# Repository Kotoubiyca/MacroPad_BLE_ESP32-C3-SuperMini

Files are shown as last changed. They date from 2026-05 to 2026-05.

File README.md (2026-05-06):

# MacroPad_BLE_ESP32-C3-SuperMini

Print project published at [MakerWorld](https://makerworld.com/uk/models/2765469-bluetooth-macropad)

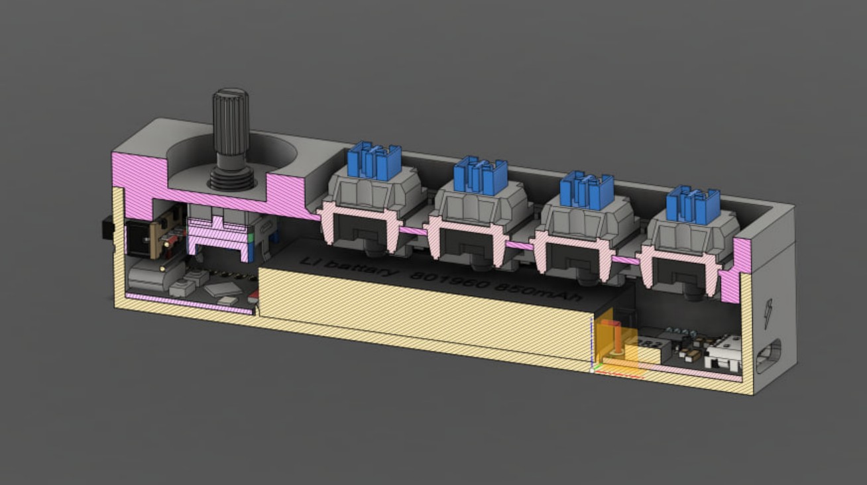
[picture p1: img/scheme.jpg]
[](/img/scheme.jpg)

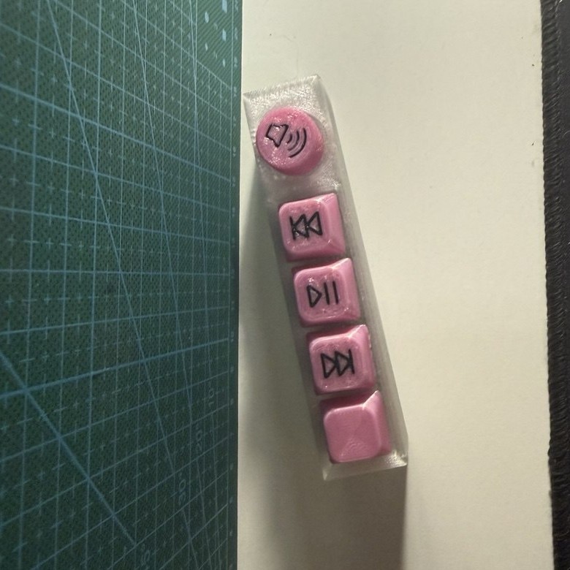
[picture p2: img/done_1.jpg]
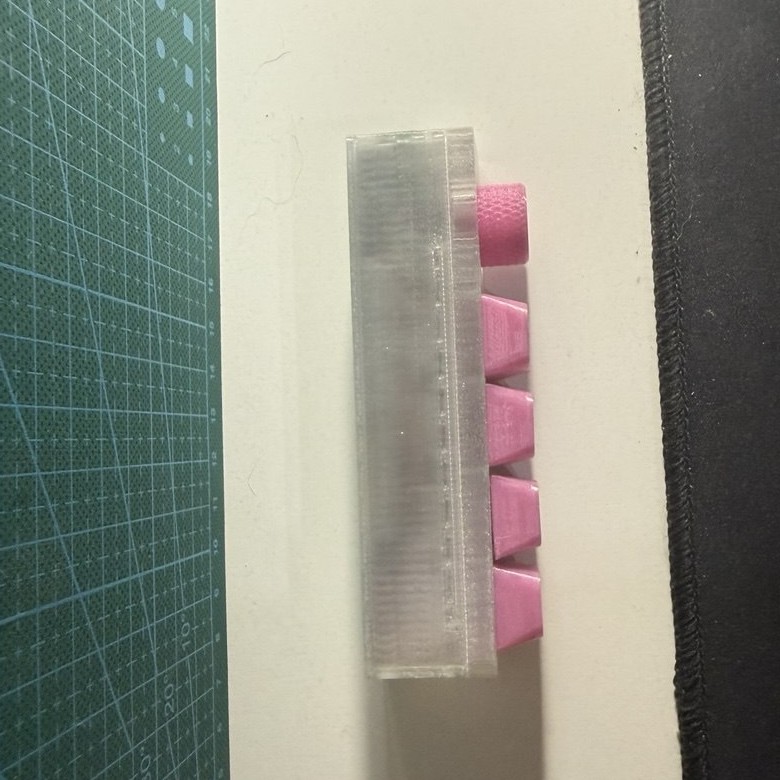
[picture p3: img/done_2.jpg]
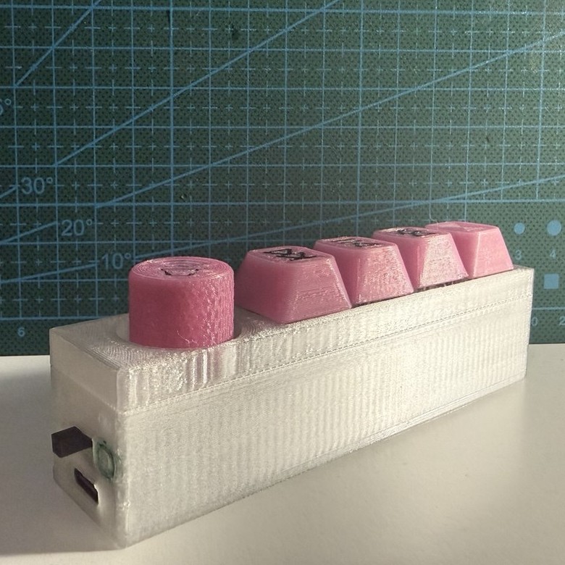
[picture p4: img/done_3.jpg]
[](/img/done_1.jpg)[](/img/done_2.jpg)[](/img/done_3.jpg)

I not like 3D-printed keycaps, but don't have factory parametric one now.

This firmware makes this device a micro Bluetooth keyboard that can be configured to control multimedia and perform any other tasks. 

I also plan to develop a version for Home Assistant using ESPhome.

## DANGER !!!
DO NOT CONNECT ESP32 port to charger or PC when power switch turned on.

## Hardware

- ESP32-C3 SuperMini

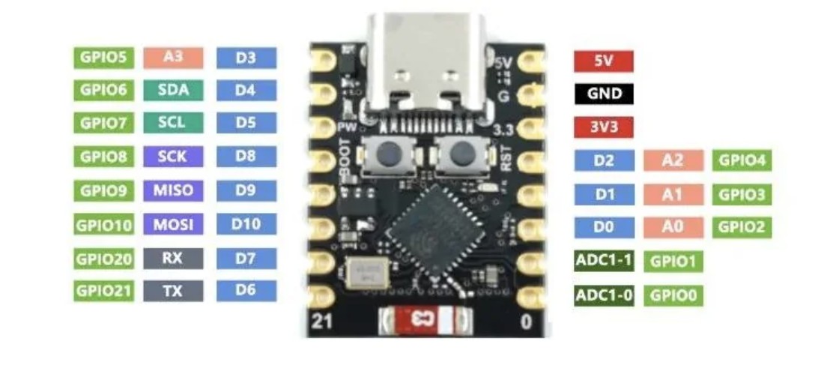
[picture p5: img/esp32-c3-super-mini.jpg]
[](/img/esp32-c3-super-mini.jpg)

- Boost Converter Step-Up Power Module for power bank based on IP5306

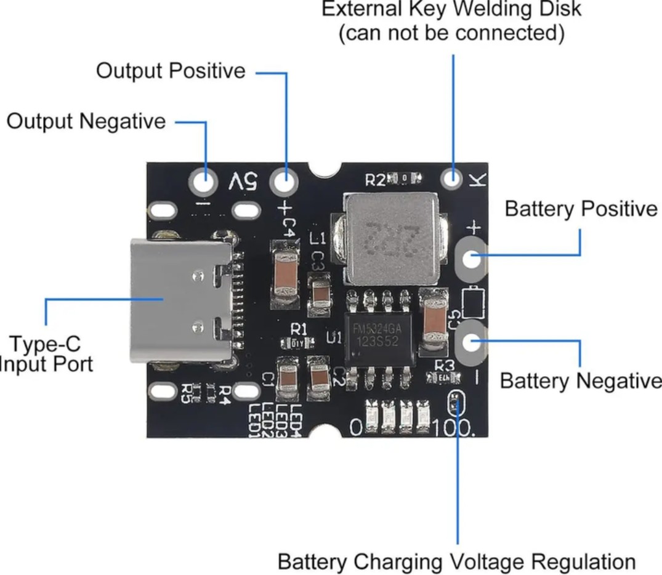
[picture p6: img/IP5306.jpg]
[](/img/IP5306.jpg)

- EC11 encoder

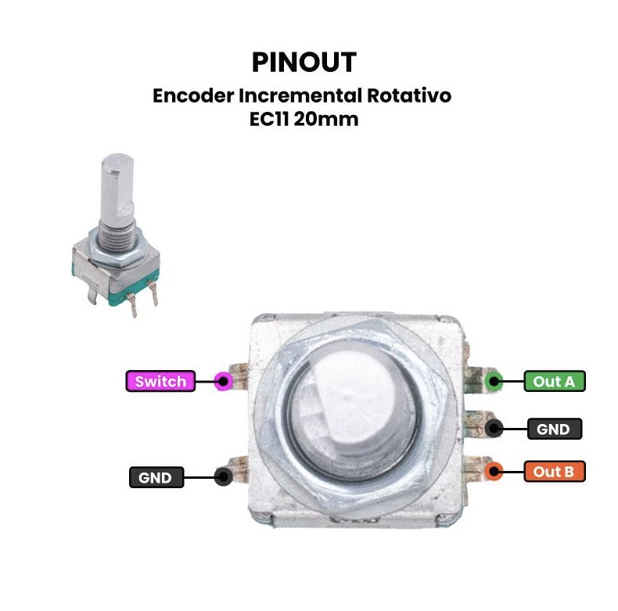
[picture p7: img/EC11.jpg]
[](/img/EC11.jpg)

- Kailh switch

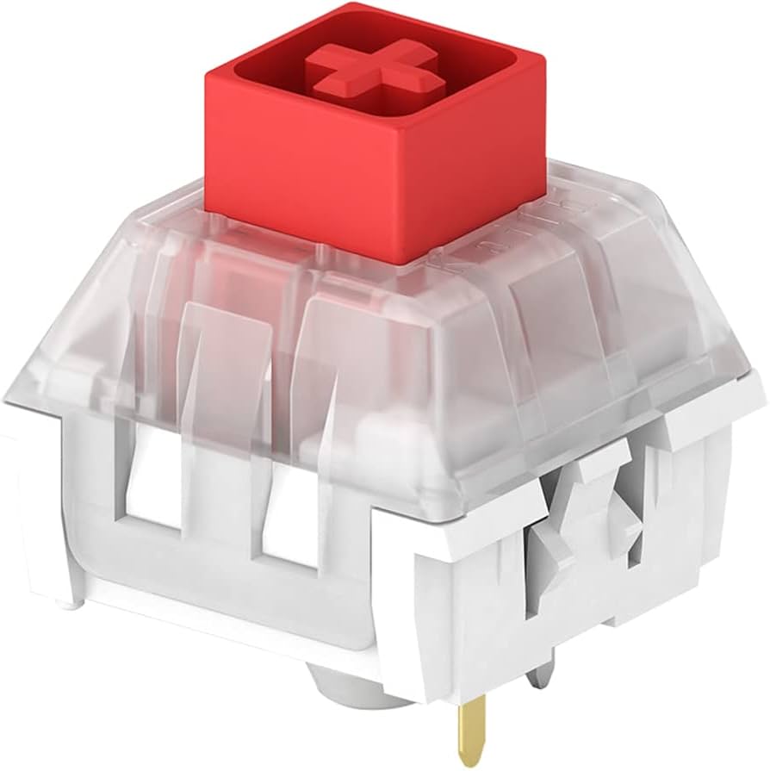
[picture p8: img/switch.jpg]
[](/img/switch.jpg)

- Kailh hot-swappable PCB Socket

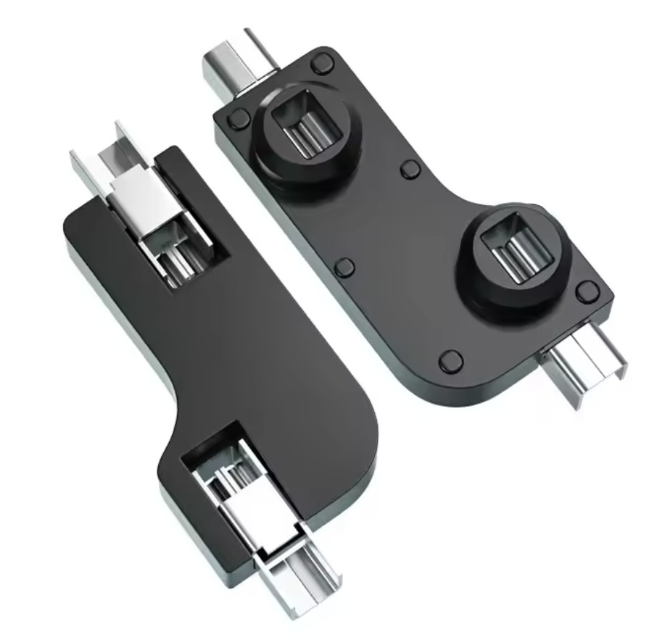
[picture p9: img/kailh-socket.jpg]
[](/img/kailh-socket.jpg)

- Slide switch SS12F15 

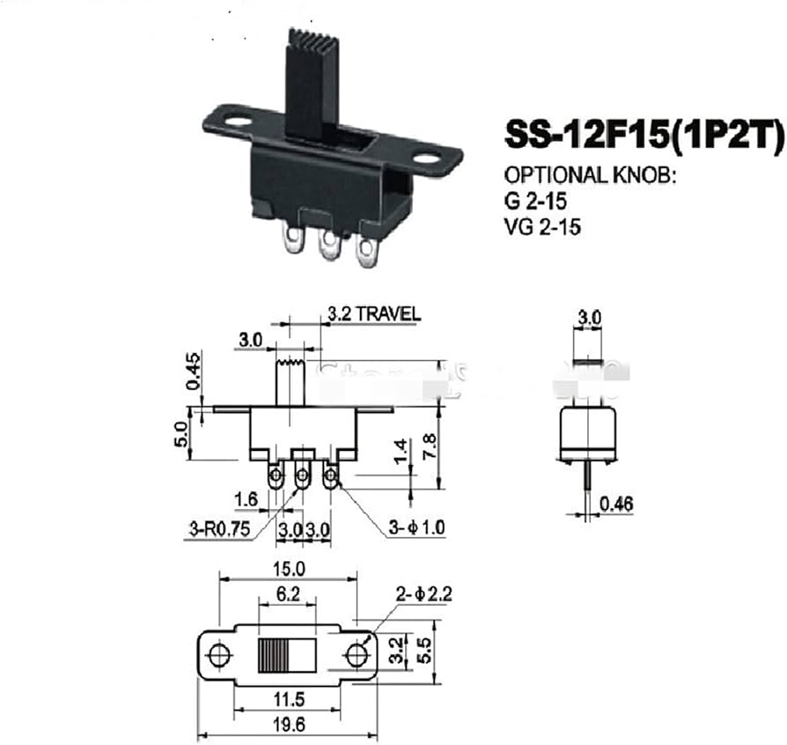
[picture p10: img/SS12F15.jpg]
[](/img/SS12F15.jpg)

- Battary Li-Pol 801960 3.7v 850mAh
(I take it from used disposable pod device 'Elf Bar Raya D3 25000')

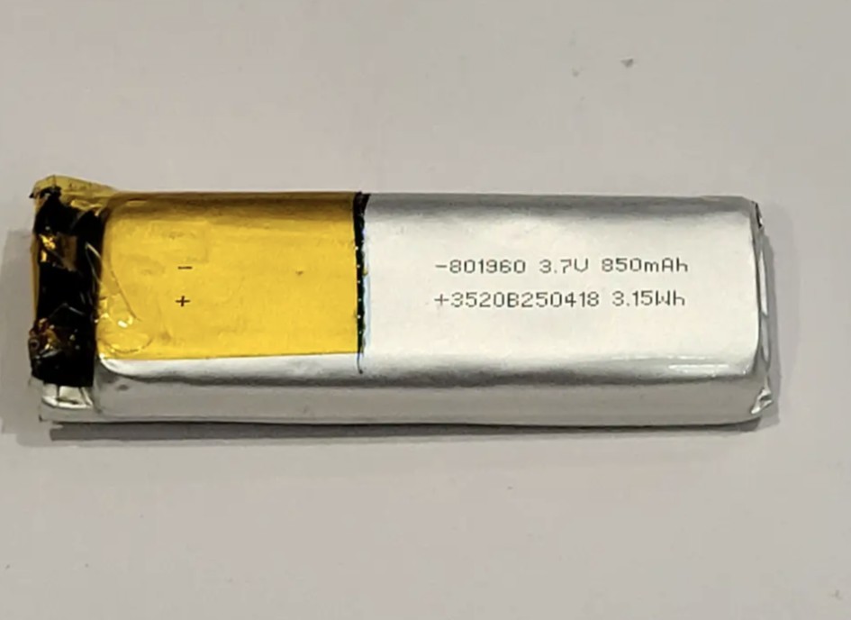
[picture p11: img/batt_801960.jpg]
[](/img/batt_801960.jpg)

## EC11 encoder connection:

| EC11 pin | ESP pin |
| --- | --- |
| C (COMMON) → | GND |
| A (CLK) → | GPIO6 |
| B (DT) → | GPIO7 |
| &nbsp; | &nbsp;  |
| SW → | GPIO8 |
| GND (SW) → | GND |

## Buttons connection:

| Button | ESP pin |
| ---| --- |
| Button 1 → | GPIO0 |
| Button 2 → | GPIO1 |
| Button 3 → | GPIO2 |
| Button 4 → | GPIO3 |
| Each 2nd pin →  | GND |

## Power connections:
- `battary` `+/-` to `bat pins` on `Power Module`  
- `Power Module` `+` → (one of side pins) `Slide switch SS12F15` (center pin) → `ESP32-C3 SuperMini` `5v` pin
- `Power Module` `-` → `ESP32-C3 SuperMini` `GND` pin

## If you some reason change or mix pins
Rename local_pins.example.hpp to local_pins.hpp and difine your pins here.

## Turn on logs
Set in src/debug.hpp `DEBUG_ENABLED` to 1

## Config
To enter in settings mode __push&hold__ encoder and turn on power then hotspot will up.
Here settings for button actions and time for soft sleeep.

- Wi-Fi Hotspot:
- ESP32-MacroPad-Config
- password: 12345678

Config page should automatic open in browser if not  go to http://192.168.4.1

## Wire connection example
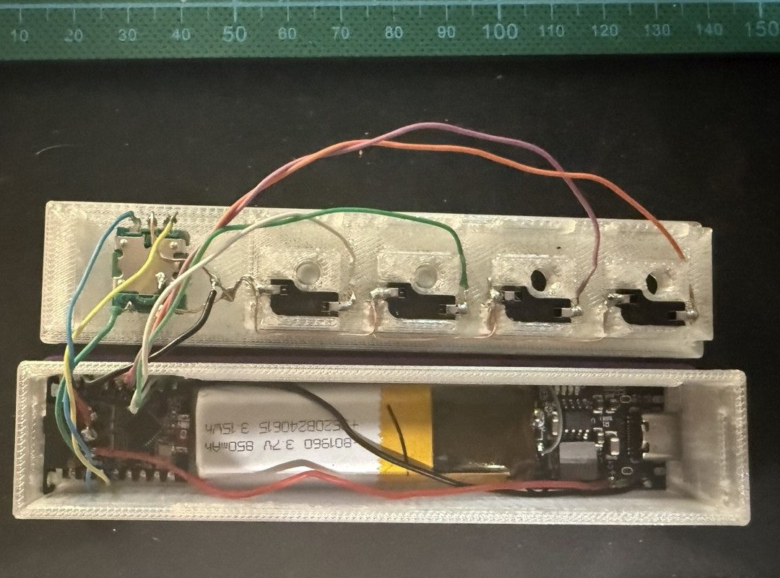
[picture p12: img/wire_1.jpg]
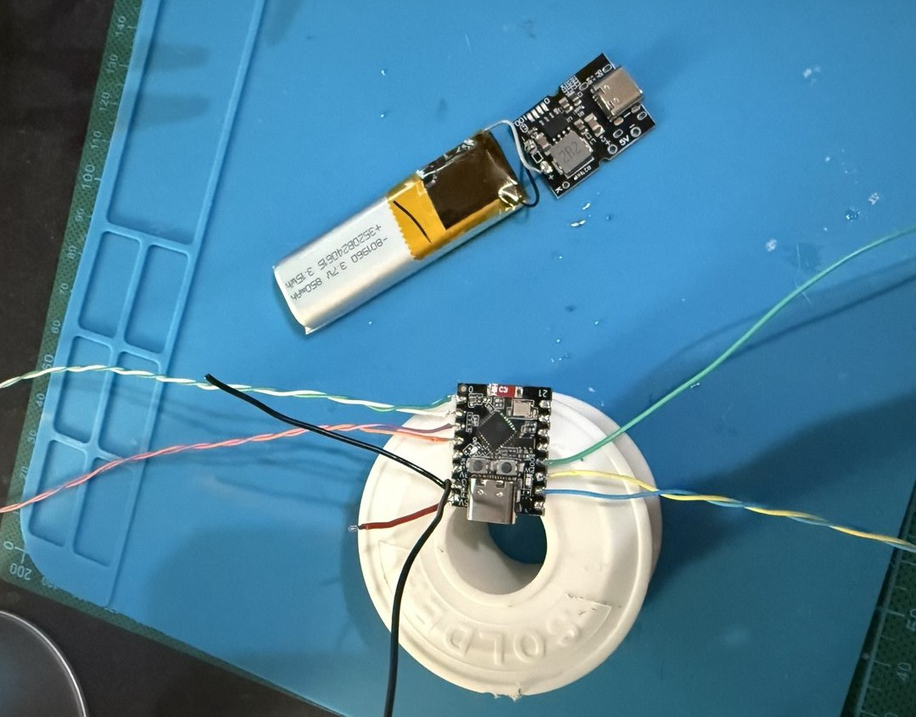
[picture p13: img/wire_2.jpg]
[](/img/wire_1.jpg) [](/img/wire_2.jpg)

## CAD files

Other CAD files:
cad_source/MacroPad.f3z

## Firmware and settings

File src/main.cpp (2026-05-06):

#include <Arduino.h>

#include "pins.hpp"
#include "state.hpp"
#include "actions.hpp"
#include "config.hpp"
#include "web.hpp"
#include "sleep.hpp"
#include "debug.hpp"

static unsigned long lastBleCheckMs = 0;

void handleBleReconnectWatchdog() {
  if (millis() - lastBleCheckMs < 5000) return;
  lastBleCheckMs = millis();

  if (!keyboard.isConnected()) {
    DBGF("BLE not connected, waiting for host reconnect...");
  }
}

void setup() {
  Serial.begin(115200);

  pinMode(ENC_CLK, INPUT_PULLUP);
  pinMode(ENC_DT, INPUT_PULLUP);
  pinMode(ENC_SW, INPUT_PULLUP);

  for (int i = 0; i < BUTTON_COUNT; i++) {
    pinMode(BUTTON_PINS[i], INPUT_PULLUP);
  }

  delay(300);

  loadConfig();

  if (digitalRead(ENC_SW) == LOW) {
    configMode = true;
    startConfigMode();
    return;
  }

  keyboard.setLogLevel(HIDLogLevel::Normal);
  keyboard.begin();

  initSleepTimer();

  lastClk = digitalRead(ENC_CLK);

  DBGF("Normal BLE mode started");
}

void loop() {
  if (configMode) {
    handleConfigWeb();
    delay(2);
    return;
  }

  handleEncoder();
  handleButtons();

  handleAutoSleep();
  
  handleBleReconnectWatchdog();
}

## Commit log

2026-05-06 init - first work version / only encoder
2026-05-06 add buttons & webconfig
2026-05-06 add custom option for button in config
2026-05-06 adding slip & debug mode & untracked local pin config
    [main.cpp]
2026-05-06 update readme & add demug mode & add printed parts
    [EC11 Knob_with volume logo.stl, MacroPadXTX_bottom.stl, MacroPadXTX_top.stl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]
2026-05-06 add MakerWorld link
    [EC11 Knob_with volume logo.stl, MacroPadXTX_bottom.stl, MacroPadXTX_top.stl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]
2026-08-24 add cad project
    [MacroPad.f3z]
